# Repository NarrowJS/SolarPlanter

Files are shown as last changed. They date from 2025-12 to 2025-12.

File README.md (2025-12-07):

# SolarPlanter

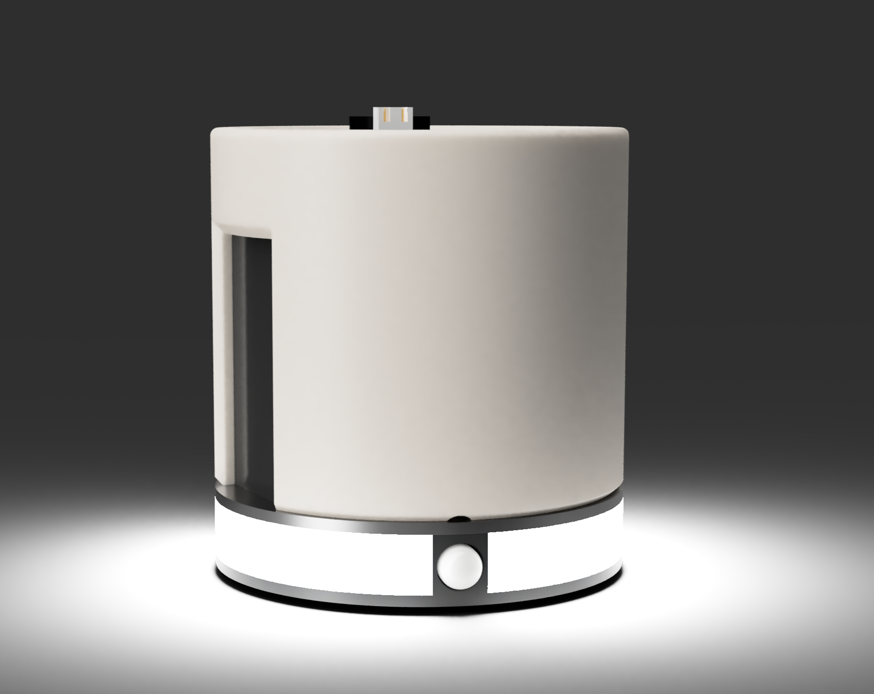
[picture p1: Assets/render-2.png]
Image of Planter

A solar powered smart planter with built in soil moisture level monitoring.

## Key Features

- **ESP32-C3** microcontroller with WiFi + BLE Support
- **650 MAH** LiPo for backup power
- Built in **RGB LEDS** for notifications
- **Online logging** and monitoring via ESPHome
- **Motion sensor** to provide relevant notifications
- **ADC** to monitor battery voltage levels

## Why?

Keeping track of your plant's mositure, knowing when to water it, and also remembering to water it can be a challenging task, especially if you have more than one plant. Wanting a solution that was discrete and did not need me to ever charge the battery led me to make SolarPlanter.

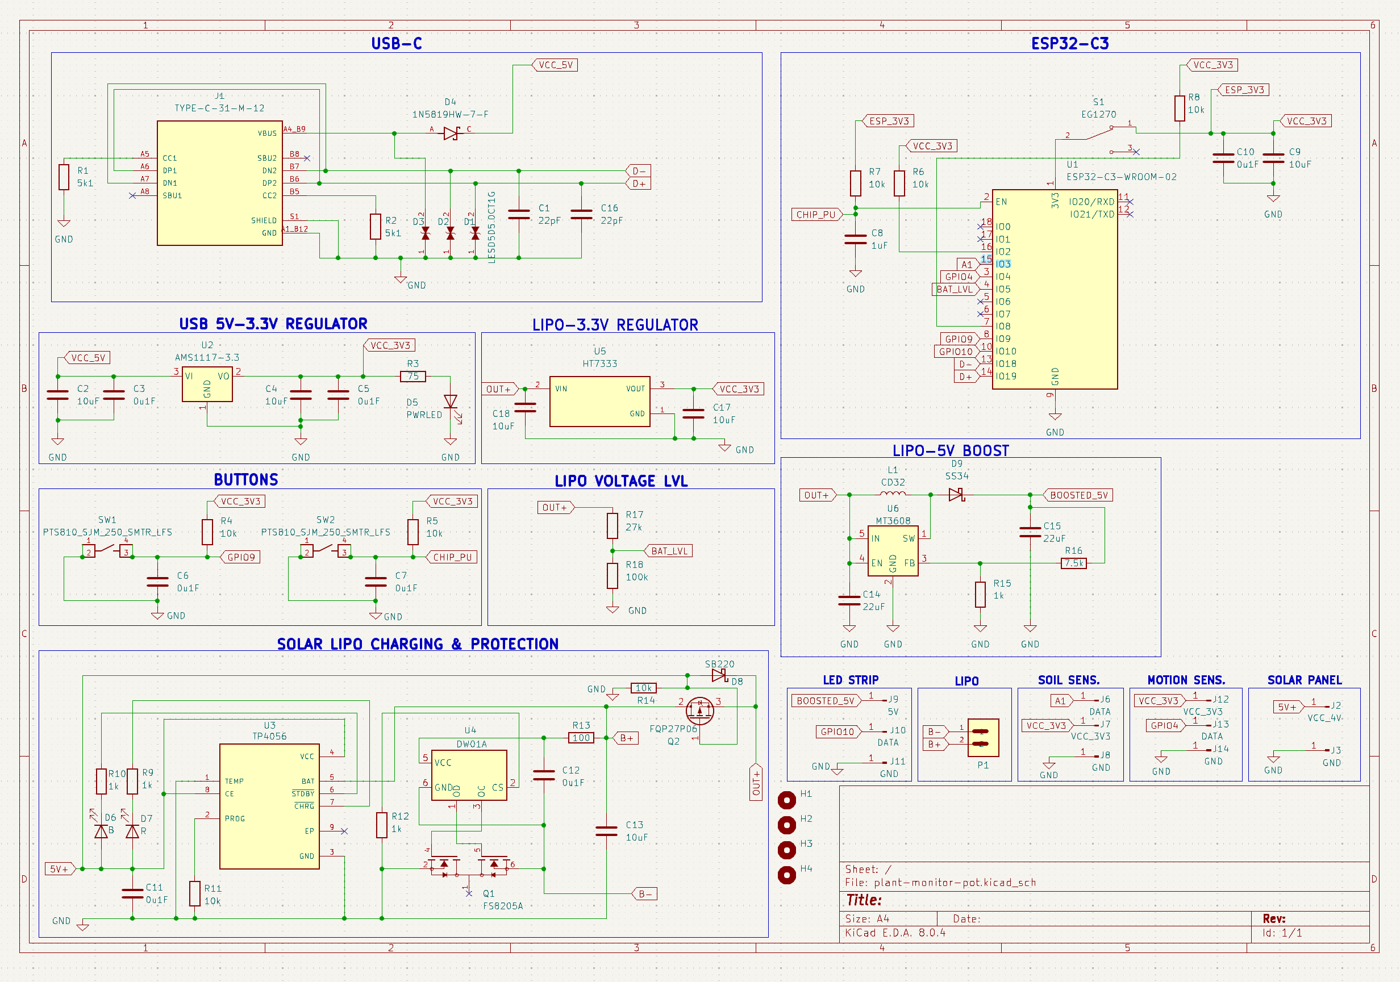
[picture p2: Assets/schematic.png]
Image of schematic

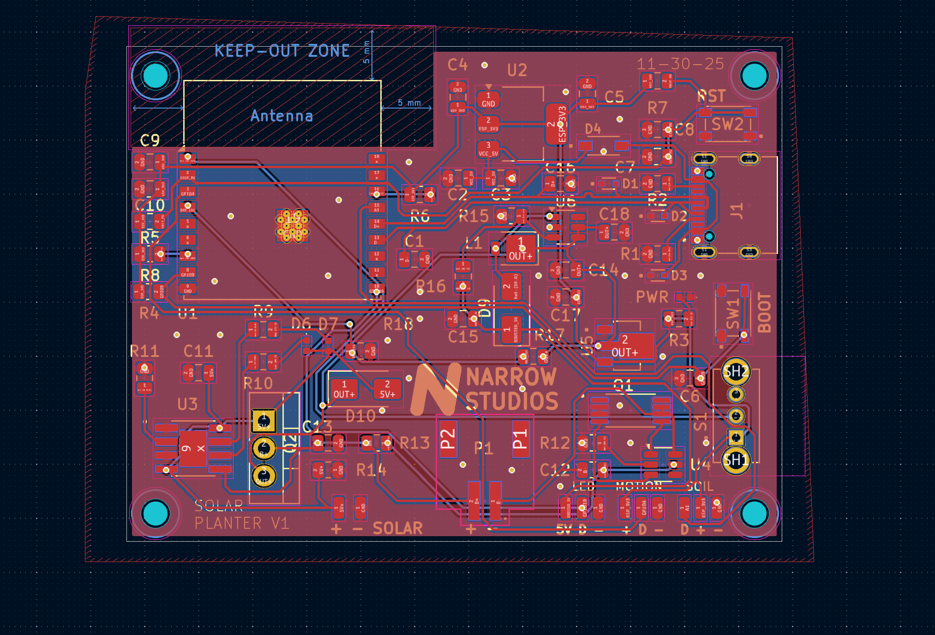
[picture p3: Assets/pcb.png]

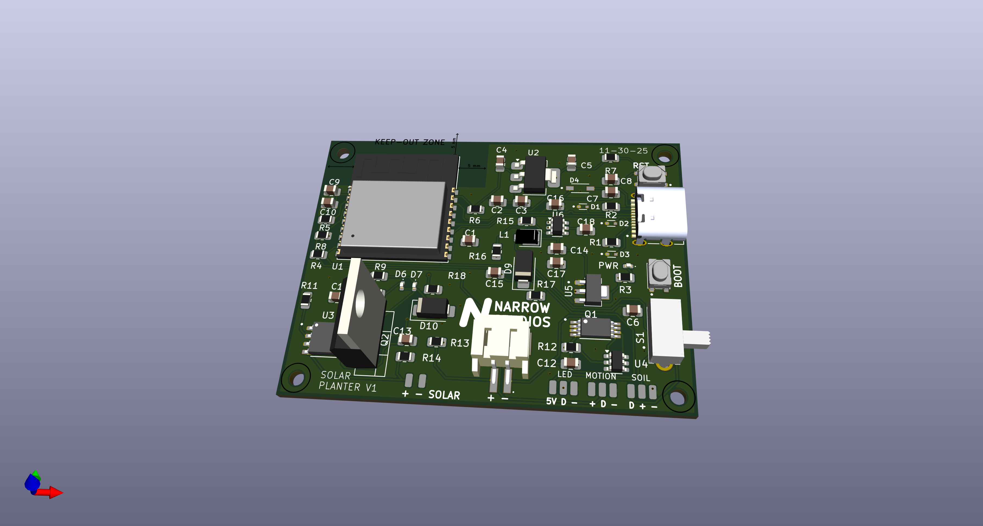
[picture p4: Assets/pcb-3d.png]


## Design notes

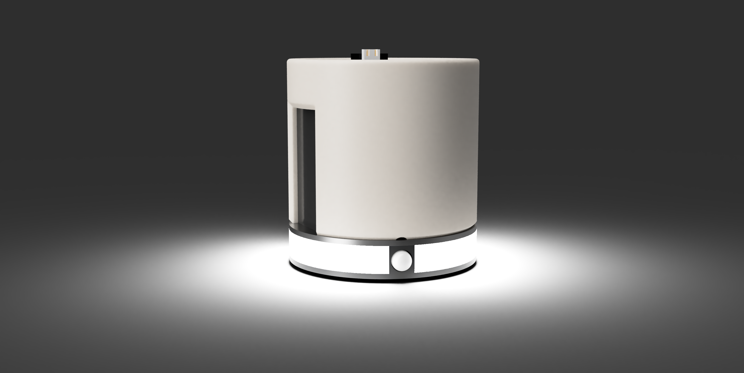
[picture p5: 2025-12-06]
Assets/render-1.png

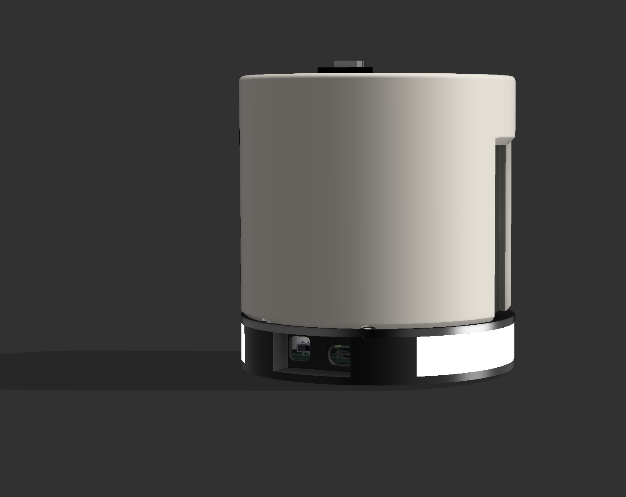
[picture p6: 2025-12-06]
Assets/photo.png

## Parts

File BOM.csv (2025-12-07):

Item | Link | Cost $ | Amount
3.7v 650mah LiPo | https://www.aliexpress.us/item/3256807419336982.html | 5.29 | 1
5v solar panel 36mm x 68mm | https://www.aliexpress.us/item/3256809302365890.html | 2.16 | 1
Capacitive Soil Moisture Sensor | https://www.aliexpress.us/item/3256809419679535.html | 3.11 | 1
HC-SR505 Motion Sensor | https://www.aliexpress.us/item/3256809235678091.html | 2.95 | 1
WS2812B LED Strip 1m 5V | https://www.aliexpress.us/item/3256809394528958.html | 7.34 | 1
M2 Bolts 3mm | https://www.amazon.com/Deal4GO-10-Pack-Replacement-Phillips-Heatsink/dp/B0B1Q9QQ7F | 3.99 | 4
M3 Bolts 3mm | https://www.amazon.com/Socket-Stainless-Threaded-Furniture-Printing/dp/B0DKXDW615 | 6.14 | 5

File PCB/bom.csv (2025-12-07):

Designator | Footprint | Quantity | Value | LCSC Part #
C1, C16 | 805 | 2 | 22pF | C1804
C10, C11, C12, C3, C5, C6, C7 | 805 | 7 | 0u1F | C3018562
C13, C17, C18, C2, C4, C9 | 805 | 6 | 10uF | C95841
C14, C15 | 805 | 2 | 22uF | C98190
C8 | 805 | 1 | 1uF | C2167365
D1, D2, D3 | TVS_LESD5D5.0CT1G | 3 | LESD5D5.0CT1G | C5199850
D10 | D_SMA | 1 | SS24 | C5190156
D4 | SOD3715X145N | 1 | 1N5819HW-7-F | C82544
D6 | 402 | 1 | B | C598348
D7 | 402 | 1 | R | C598349
D9 | D_SMA | 1 | SS34 | C8678
J1 | HRO_TYPE-C-31-M-12 | 1 | TYPE-C-31-M-12 | C165948
L1 | D_SMP_DO-220AA | 1 | CD32 | C41408473
P1 | JST_S2B-PH-SM4-TB | 1 | S2B-PH-SM4-TB | C295747
PWR | 402 | 1 | PWRLED | C598352
Q1 | SOP65P640X120-8N | 1 | FS8205A | C2830320
Q2 | TO-220-3_Vertical | 1 | FQP27P06 | C7503194
R1, R2 | 805 | 2 | 5k1 | C122968
R10, R12, R15, R9 | 805 | 4 | 1k | C95781
R11, R14, R4, R5, R6, R7, R8 | 805 | 7 | 10k | C84376
R13 | 805 | 1 | 100 | C17408
R16 | 805 | 1 | 7.5k | C17807
R17 | 805 | 1 | 27k | C17593
R18 | 805 | 1 | 100k | C96346
R3 | 805 | 1 | 75 | C17820
S1 | SW_EG1247 | 1 | EG1247 | C431548
SW1, SW2 | SW_PTS810_SJM_250_SMTR_LFS | 2 | PTS810_SJM_250_SMTR_LFS | C116501
U1 | ESP32-C3-WROOM-02 | 1 | ESP32-C3-WROOM-02 | C2934560
U2 | SOT-223-3_TabPin2 | 1 | AMS1117-3.3 | C6186
U3 | SOP127P600X175-9N | 1 | TP4056 | C382139
U4 | SOT-23-6 | 1 | DW01A | C2927799
U5 | IC_HT7333 | 1 | HT7333 | C7434186
U6 | SOT-23-6 | 1 | MT3608 | C84817

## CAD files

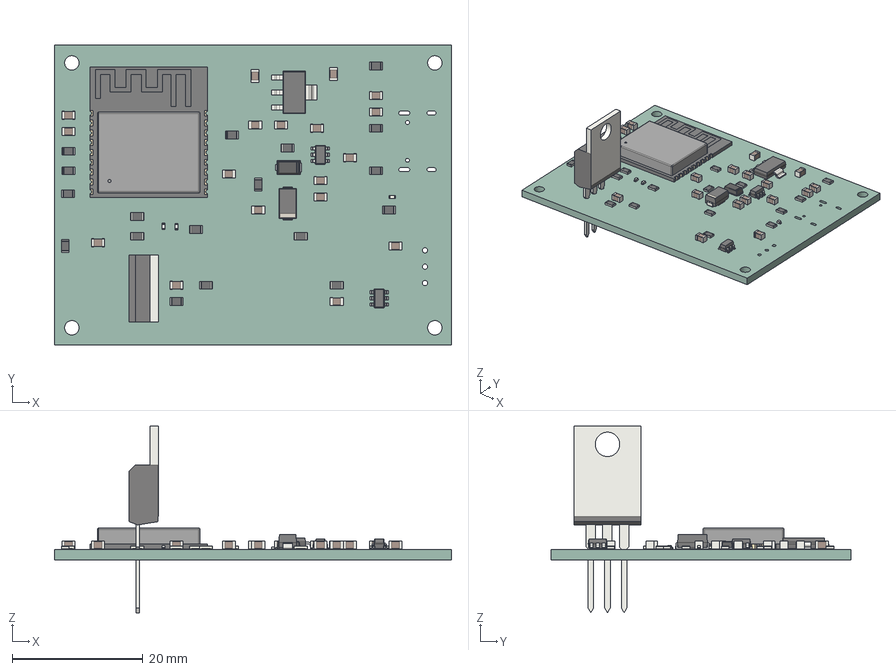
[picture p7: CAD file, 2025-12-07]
PCB/plant-monitor-pot.step
60.7 x 45.8 x 28.5 mm
R_0805_2012Metric x 18
D_SMP_DO_220AA_cp
SOT_223
SOT_23_6 x 2
C_0805_2012Metric x 18
TO-220-3_Vertical
ESP32-C3-WROOM-02
LED_0402_1005Metric x 3
D_SMA
plant-monitor-pot_PCB

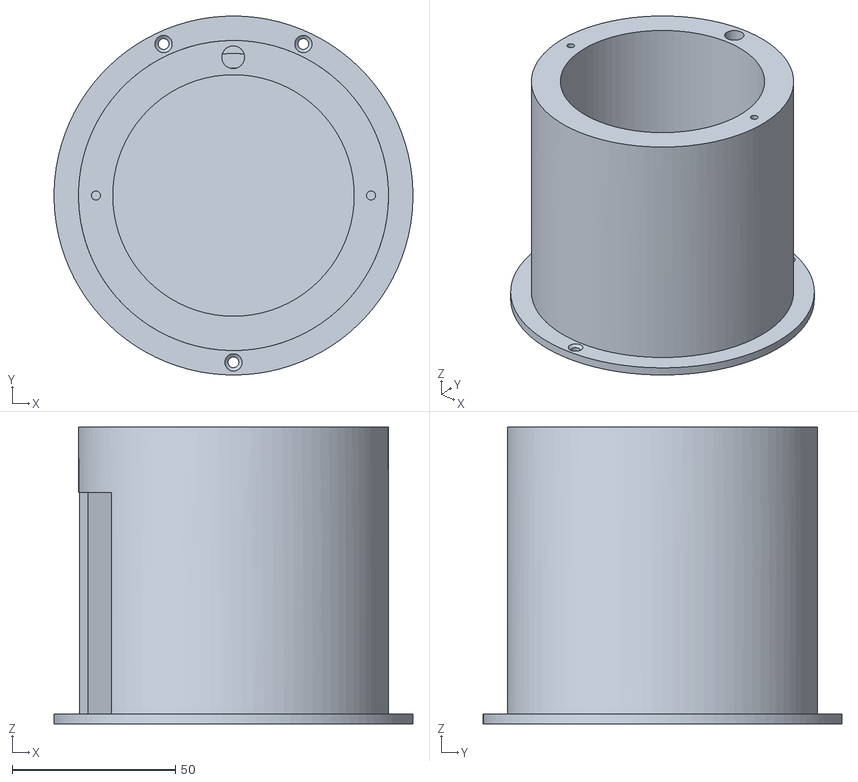
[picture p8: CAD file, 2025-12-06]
STLs/base-lid.stl
109.9 x 110.0 x 91.0

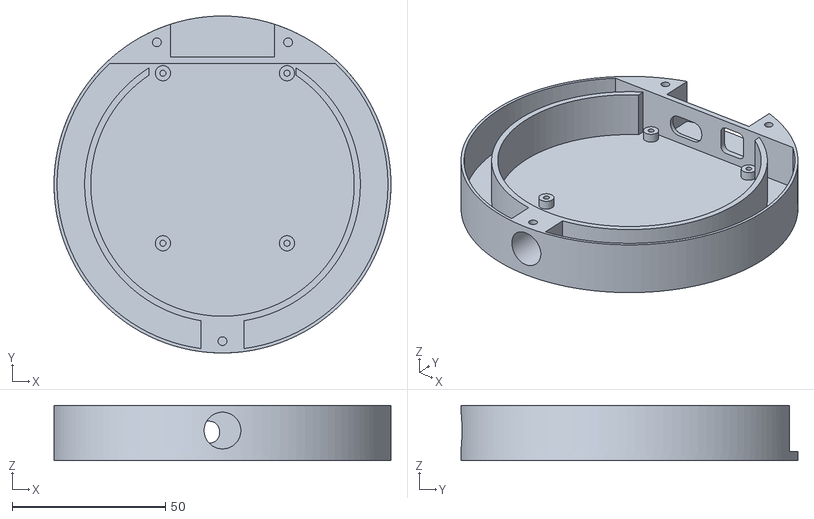
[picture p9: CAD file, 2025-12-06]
STLs/base.stl
110.0 x 110.0 x 18.0

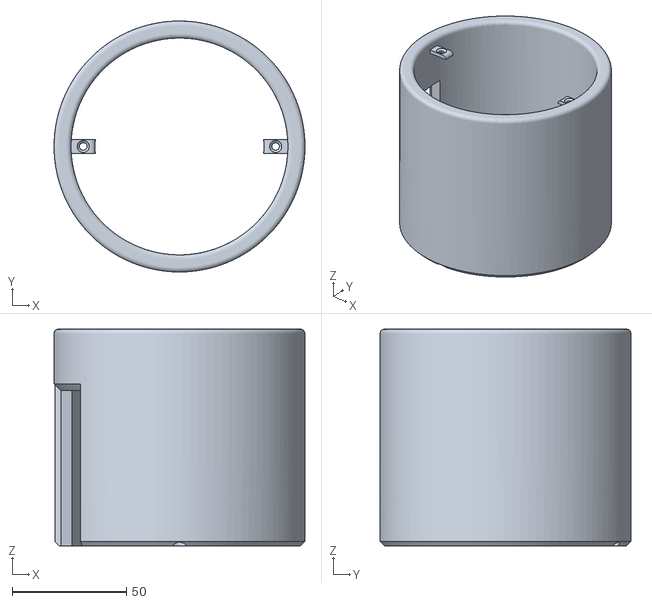
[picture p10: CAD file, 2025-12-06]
STLs/outer-lid.stl
110.0 x 110.0 x 95.0

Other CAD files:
CAD/plant-monitor-pot.f3d

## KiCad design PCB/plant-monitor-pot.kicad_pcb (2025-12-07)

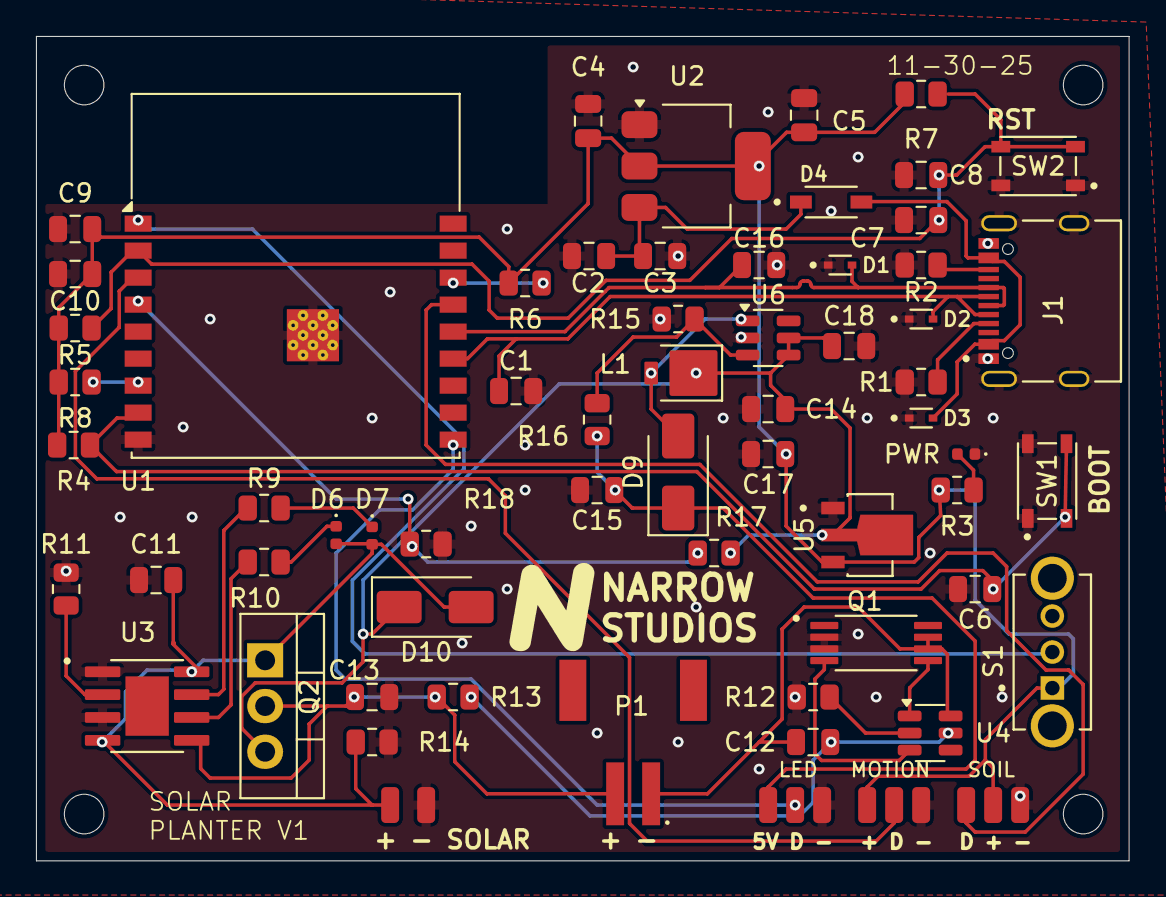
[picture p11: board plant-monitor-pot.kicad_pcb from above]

Board: 2 copper layers, 60.7 x 45.8 mm, 75 parts (0 on the bottom side), 34 nets.

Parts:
C1, C16: 22pF; C_0805_2012Metric
C2, C4, C9, C13, C17, C18: 10uF; C_0805_2012Metric
C3, C5, C6, C7, C10, C11, C12: 0u1F; C_0805_2012Metric
C8: 1uF; C_0805_2012Metric
C14, C15: 22uF; C_0805_2012Metric
D1, D2, D3: LESD5D5.0CT1G; TVS_LESD5D5.0CT1G
D4: 1N5819HW-7-F; SOD3715X145N
D6: B; LED_0402_1005Metric
D7: R; LED_0402_1005Metric
D9: SS34; D_SMA
D10: SS24; D_SMA
H1, H2, H3, H4: MountingHole; MountingHole_2.2mm_M2
J1: TYPE-C-31-M-12; HRO_TYPE-C-31-M-12
J2: VCC_4V; SolderWirePad_1x01_SMD_1x2mm
J3, J8, J11, J14: GND; SolderWirePad_1x01_SMD_1x2mm
J6, J10, J13: DATA; SolderWirePad_1x01_SMD_1x2mm
J7, J12: VCC_3V3; SolderWirePad_1x01_SMD_1x2mm
J9: 5V; SolderWirePad_1x01_SMD_1x2mm
L1: CD32; D_SMP_DO-220AA
P1: S2B-PH-SM4-TB; JST_S2B-PH-SM4-TB
PWR: PWRLED; LED_0402_1005Metric
Q1: FS8205A; SOP65P640X120-8N
Q2: FQP27P06; TO-220-3_Vertical
R1, R2: 5k1; R_0805_2012Metric
R3: 75; R_0805_2012Metric
R4, R5, R6, R7, R8, R11, R14: 10k; R_0805_2012Metric
R9, R10, R12, R15: 1k; R_0805_2012Metric
R13: 100; R_0805_2012Metric
R16: 7.5k; R_0805_2012Metric
R17: 27k; R_0805_2012Metric
R18: 100k; R_0805_2012Metric
S1: EG1247; SW_EG1247
SW1, SW2: PTS810_SJM_250_SMTR_LFS; SW_PTS810_SJM_250_SMTR_LFS
U1: ESP32-C3-WROOM-02
U2: AMS1117-3.3; SOT-223-3_TabPin2
U3: TP4056; SOP127P600X175-9N
U4: DW01A; SOT-23-6
U5: HT7333; IC_HT7333
U6: MT3608; SOT-23-6
e: LOGO; ns-logo

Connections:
5V+: C11.1, D6.2 (A), D7.2 (A), D10.2 (A), J2.1, Q2.1 (G), R14.2, U3.4 (VCC), U3.8 (CE)
A1: J6.1, U1.15 (IO3)
B+: C13.1, P1.2, Q2.2 (D), R13.2, U3.5 (BAT)
B-: C12.2, P1.1, Q1.6, Q1.7, U4.6 (GND)
BAT_LVL: R17.2, R18.1, U1.4 (IO5)
BOOSTED_5V: C15.1, D9.1 (K), J9.1, R16.2
CHIP_PU: C7.1, C8.1, R5.2, R7.2, SW2.3, SW2.4, U1.2 (EN)
D+: C16.1, D1.2, J1.A6 (DP1), J1.B6 (DP2), U1.14 (IO19)
D-: C1.1, D2.2, J1.A7 (DN1), J1.B7 (DN2), U1.13 (IO18)
ESP_3V3: C4.1, C5.1, C9.1, C10.1, C17.1, J7.1, J12.1, R3.1, R4.1, R5.1, R6.1, R7.1, R8.1, S1.1, U2.2 (VO), U5.3 (VOUT)
GND: C1.2, C2.2, C3.2, C4.2, C5.2, C6.2, C7.2, C8.2, C9.2, C10.2, C11.2, C13.2, C14.2, C15.2, C16.2, C17.2, C18.2, D1.1, D2.1, D3.1, J1.A1_B12 (GND), J1.B1_A12 (GND), J1.S1 (SHIELD), J1.S2 (SHIELD), J1.S3 (SHIELD), J1.S4 (SHIELD), J3.1, J8.1, J11.1, J14.1, PWR.1 (K), Q1.2, Q1.3, R1.2, R2.2, R11.2, R12.2, R14.1, R15.2, R18.2, SW1.1, SW1.2, SW2.1, SW2.2, U1.9 (GND), U1.19 (GND), U2.1 (GND), U3.1 (TEMP), U3.3 (GND), U5.1 (GND), U6.2 (GND)
GPIO4: J13.1, U1.3 (IO4)
GPIO9: C6.1, R4.2, SW1.3, SW1.4, U1.8 (IO9)
GPIO10: J10.1, U1.10 (IO10)
unnamed: PWR.2 (A), R3.2
unnamed: D6.1 (K), R10.2
unnamed: D7.1 (K), R9.2
unnamed: D9.2 (A), L1.2, U6.1 (SW)
unnamed: J1.A5 (CC1), R1.1
unnamed: J1.B5 (CC2), R2.1
unnamed: S1.2, U1.1 (3V3)
unnamed: R6.2, U1.16 (IO2)
unnamed: R8.2, U1.7 (IO8)
unnamed: R11.1, U3.2 (PROG)
unnamed: R9.1, U3.7 (~CHRG)
unnamed: R10.1, U3.6 (~STDBY)
unnamed: R12.1, U4.2 (CS)
unnamed: Q1.4, U4.3 (OC)
unnamed: Q1.5, U4.1 (OD)
unnamed: C12.1, R13.1, U4.5 (VCC)
unnamed: R15.1, R16.1, U6.3 (FB)
OUT+: C14.1, C18.1, D10.1 (K), L1.1, Q2.3 (S), R17.1, U5.2 (VIN), U6.4 (EN), U6.5 (IN)
VBUS: D3.2, D4.A, J1.A4_B9 (VBUS), J1.B4_A9 (VBUS)
VCC_5V: C2.1, C3.1, D4.C, U2.3 (VI)

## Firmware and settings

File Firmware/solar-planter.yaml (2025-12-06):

esphome:
  name: solar-planter
  platform: ESP32
  board: esp32_c3

esp32:
  variant: ESP32C3
  board: esp32-c3-devkitm-1
  framework:
    type: esp-idf

wifi:
  ssid: !secret wifi_ssid
  password: !secret wifi_password

logger:

api:

web_server:
  port: 80

ota:

deep_sleep:
  run_duration: 10s
  sleep_duration: 60min

sensor:
  - platform: adc
    pin: GPIO3
    name: "Soil Moisture Voltage"
    unit_of_measurement: "V"
  - platform: adc
    pin: GPIO5
    name: "LiPo Voltage"
    unit_of_measurement: "V"

binary_sensor:
  - platform: gpio
    pin: GPIO4
    name: "PIR Sensor"
    lambda: return esp_sleep_get_wakeup_cause();
    device_class: motion

light:
  - platform: esp32_rmt_led_strip
    rgb_order: GRB
    pin: GPIO10
    num_leds: 30
    chipset: ws2812
    name: "Status Light"

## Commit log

2025-12-07 pcb v2
    changed pcb, photo, and upload new bom
    [BOM.csv, bom.csv, plant-monitor-pot.kicad_pcb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]
2025-12-07 Revert "pcb v2"
    [BOM.csv, bom.csv, plant-monitor-pot.kicad_pcb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]
2025-12-07 new pcb
    [bom.csv, plant-monitor-pot.kicad_pcb, plant-monitor-pot.step]
2025-12-07 changed the pcb and bom
    [BOM.csv, plant-monitor-pot-pcb.step]
2025-12-07 updated main parts BOM
    [BOM.csv]
2025-12-07 changed bom to not duplicate
    [BOM.csv, bom.csv]
2025-12-07 removed both boms
    [BOM.csv, bom.csv]
2025-12-07 added back bom
    [bom.csv]
2025-12-07 updated bom layout
2025-12-07 updated bom v2
    [bom.csv]
2025-12-07 added pcb render
